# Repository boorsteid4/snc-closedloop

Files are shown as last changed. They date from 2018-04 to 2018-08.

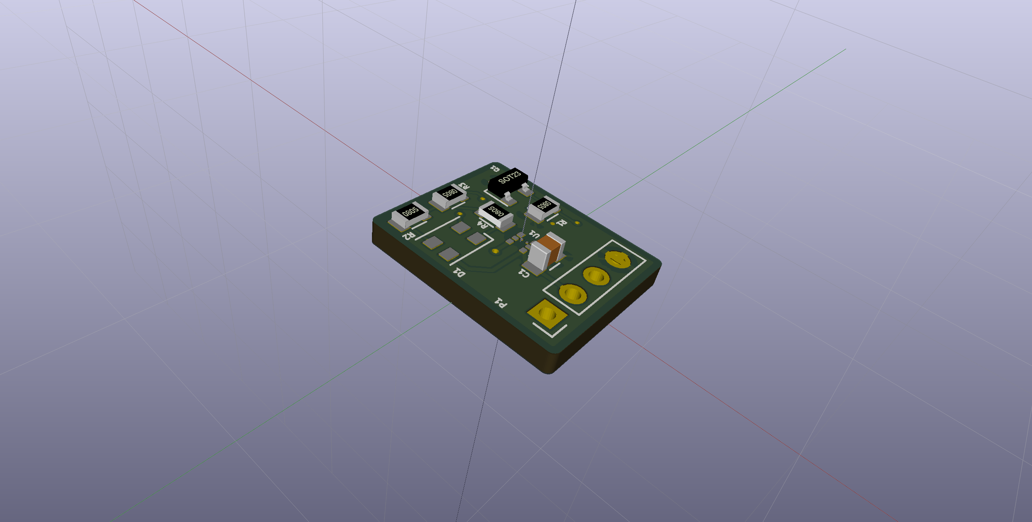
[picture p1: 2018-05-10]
Documentation/fig/LightBoardLayout.png

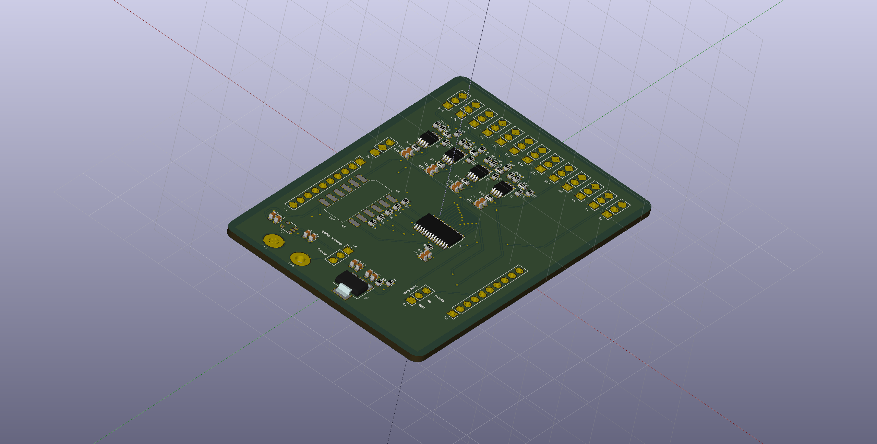
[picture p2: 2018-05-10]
Documentation/fig/LightBoardIMG.png

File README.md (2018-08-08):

# Automatic Light Dimming System
Welcome to the Git repo for our Systems and Control Spring 2018 final project! We are designing an automatic light dimming system with PID control. This top directory gives a general overview of the project.

## Contents

* [Hardware](#hardware)
* [Code Structure](#code-structure)
* [Documentation](#documentation)
* [PCB](#pcb)
* [SolidWorks](#solidworks)

## Hardware
The hardware for this project consists of:
* 1 MSP430FR2433 LaunchPad Development Kit by Texas Instruments
* 1 custom central control daughter card (CentralBoard)
* 13 custom LED/light sensor boards (LightBoard)  
    *  9 for the LED array  
    *  4 for the sensor array

The MSP430FR2433 serves as the processor on which the control system will be implemented. The daughter card includes an LED driver, transimpedance amplifiers for the light sensor inputs, and connectors for the power supply and motor. The transimpedance amplifiers were placed on the daughter card in order to minimize the space needed for each individual LightBoard since there will be so many of them placed inside our box. The LEDs and sensors were made into one board in an effort to minimize the cost of this project.

## Code Structure
* **main.c** - The top level entity of this project.
* **Controller.c/.h** - These files define a structure to contain all of the data that is necessary to implement a control system. It also includes a number of functions used to update the controls system.

Code can be found [here](Code).

## Documentation
[This subdirectory](Documentation) contains documentation for the project. Our project proposal, final report, and all refrences are contained herein. Images, figures, and hardware datasheets can also be found here. 

## PCB
PCBs were designed for this project. [This subdirectory](PCB) has all relevant project files, including schematics and layouts.

## SolidWorks
Solidworks designs created for the project thus far can be found in [this subdirectory](SLDWK).

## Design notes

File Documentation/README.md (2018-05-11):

# Documentation Catalog

| Author 	| Company Catalog No. 	| Description 		| Link				|
|---|---|---|:---:|
|Boorstein & Souder	|			|Project Proposal			 		|[Project Proposal](Final_Project_Proposal-Systems_and_Control.pdf)	|
|Boorstein & Souder  	|			|Final Project Report			 		|[Final Project Report](09321_1_Boorstein_Souder.pdf)		  	|
|Boorstein & Souder 	|			|Bill of Materials			 		|[BOM](bom/Bill-of-Materials.pdf)					|
|Boorstein & Souder  	|			|Light Board Bill of Materials		 		|[BOM](bom/LightBoard_BOM.pdf)				 	 	|
|Boorstein & Souder  	|			|Light Controller Bill of Materials	 		|[BOM](bom/LightController_BOM.pdf)					|
|Texas Instruments	|SLASE59B		|MSP430FR2433 Mixed-Signal Microcontroller  		|[DS](ds_ug/msp430fr2433.pdf)					 	|
|Damon Boorstein  	|			|System Block Diagram			 		|[FIG](fig/block_diagram.png)					 	|
|Lonnie Souder II 	|			|Light Controller Layout		 		|[FIG](fig/LightBoardIMG.png)					 	|
|Lonnie Souder II 	|			|Light Board Layout			 		|[FIG](fig/LightBoardLayout.png)					|
|Damon Boorstein 	|			|Light Controller UML			 		|[FIG](fig/LightControllerUML.png)					|
|C.M.Mak et. al.  	|			|Article on daylight and luminous comfort 		|[REF](refs/1-s2.0-S0360132314001978-main.pdf)				|
|Hwang & Kim	  	|			|Article on Samsung's new Green Building 		|[REF](refs/1420326x10392017.pdf)					|
|Lee et. al.	  	|			|Article on human response to illuminance variations	|[REF](refs/1420326x12446208.pdf)					|
|IEEE		  	|			|IEEE Std. 1789-2015					|[REF](refs/7118618.pdf)						|
|Lu et. al.	  	|			|Report on ZigBee-Based Lighting System			|[REF](refs/out.pdf)							|
|Lonnie Souder II 	|			|Light Board Schematic					|[SCH](schematic/LightBoardSchematic.png)				|
|Lonnie Souder II 	|			|Light Controller Schematic				|[SCH](schematic/LightControllerSchematic.png)				|
|Lonnie Souder II 	|			|Sensor Array Schematic					|[SCH](schematic/SensorArray.png)					|
|Lonnie Souder II 	|			|Example Transimpedance Amplifier Schematic		|[SCH](schematic/transimpedance_amp.png)				|
|Texas Instruments	|SLAU445G		|MSP430FR4xx and FR2xx Family User's Guide  		|[UG](ds_ug/slau445g.pdf)						|

### Legend

* AN - Application Note 
* DS - Datasheet 
* FIG - Figure/Image
* SCH - Schematic
* REF - Reference (Journal Article, Website, etc.)
* UG - User Guide

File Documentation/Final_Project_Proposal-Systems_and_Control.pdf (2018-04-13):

Damon Boorstein & Lonnie Souder II Dr. Al-Quzwini
Systems & Controls
March 26, 2018

Room Lighting Control System

For our final project we would like to implement an automatic room lighting control system. Instead of spending a large sum of money to light an entire room, we would like to recreate a small model of a room in a small box (roughly the size of a shoebox or slightly larger). This will allow us to set our focus on the control system instead or the logistics of lighting an entire room. The model will consist of a box that should be closed on all sides (just like any other house). On one side there will be a window consisting of automatic blinds that we plan to open and close with a small stepper or servo motor. At the top of the room there will be a light source (or possibly many light sources). There will also be light sensors inside the room and outside of the house. This will allow us to maintain full control over the level of brightness in the room at all times of day.
The basic functionality of the system is as follows. Because there is no “anti light” that we can use to dim the room even when the outside world is shining light through the window (disturbance), we have decided to use the shades to dim the room if necessary during the day, while the light source can light the room at night. For power efficiency, the system will always first take into account the desired brightness and the outside brightness. If the amount of light outside is sufficient to brighten the room to the desired level, then the light source should stay off completely and the shades will open to a point at which the room’s brightness is just right. If the outside light is not sufficient to brighten the room, then the light source will be used as a supplement.
The image below, is our rough draft model of the system as we see it so far (minus some conditionals to be implemented alongside the control system). Essentially our inputs are R1 and R2 which represent the voltage inputs to the light source and the motor controlling the blinds respectively. G1 represents the physical characteristics of the light source and its ability to convert power to light. H1 is our transfer function based off of the indoor brightness reading which is used to close the loop. G2 represents the blinds and how much light they allow through at certain angles. H2 is our transfer function based off of the outdoor brightness measurement and desired brightness, which will control the angle of the shades. As mentioned before, this is a rough model, and pieces may still be removed or added before the final submission as we find that pieces of our model are either incorrect or unnecessary.

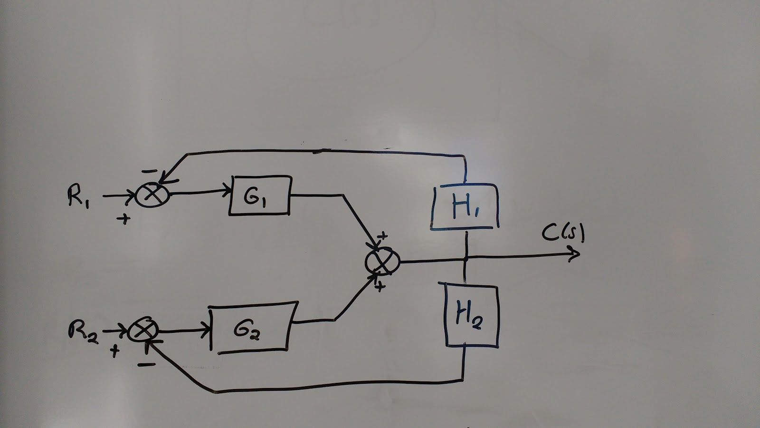
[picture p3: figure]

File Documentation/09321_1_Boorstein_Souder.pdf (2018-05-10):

– ECE 09.321: Systems and Controls –

## Automatic Light Dimming Control System Based on PID Control Design

L. Souder and D. Boorstein Section 1

May 8, 2018

## 1 Abstract

Demand for light dimming control systems is predicted to grow in the coming years with the rise in green buildings and green engineering. Current light dimming systems do not address the issue of high fluctuations in light level which can have damaging effects on occupants’ eyes. This can also affect occupants’ mental health, stress level, and productivity in the work environment. This report presents a design for a novel light dimming system based on software-implemented PID control theory. A central MSP430FR2433 is programmed to implement PID control for a negative feedback system consisting of an array of LEDs and current-output light sensors. PCBs were designed and printed. However, a final product was not fully built or tested due to several roadblocks and constraints. A fully designed system could definitely be built with additional time and effort.

## 2 Introduction

Sick building syndrome (SBS) is a condition often related to decreased productivity and increased stress, supposedly caused by deterioration of one’s interior environment [1]. This can be caused by a number of factors, including indoor lighting. Indoor lighting is an often overlooked design consideration in modern residential and work spaces, and its impact is significant on productivity and health. The Occupational Safety and Health Administration (OSHA) measures general lighting in the workplace using foot-candles as units, requiring physical plants maintain 10 foot-candles of brightness and offices at least 30 foot-candles [2]. In labor-intense environments like manufacturing plants, factories, or workshops, proper lighting ensures accident prevention, hazard avoidance, and physical safety. In the office, where these dangers are often not present, lighting contributes directly to mental health which influences

L. Souder and D. Boorstein | – ECE 09.321: Systems and Controls – | Section 1

productivity [1],[3],[4].

In 2009, Samsung World Headquarters in Seoul, Korea launched a new Energy Saving Campaign and earned the highest ranking Green Building Certification System certification by the Korean Green Building Council (KGBC). During daylight hours, half of the interior lights in the building were to be turned off to reduce power consumption [1]. During sunny days, this was no issue; during cloudy days, however, the offices were dark. This significantly affected employee mood and contributed to their annoyance ratio of their workplace [1]. Daylight can certainly improve mood and has even shown to prevent certain diseases and influence window design in residential and office buildings [3]. However, visual distractions, variation in illuminance, and high stimulation caused by improper lighting may contribute to higher amounts of annoyance and stress [4]. Higher stress can lead to decreased productivity.

As green engineering and green buildings become more popular in the coming years, the demand for light dimming control systems should also increase. Current light dimming control systems offer illumination at a fraction of the energy cost. A recent Zigbee-based indoor light control system was developed using a network of lightsensitive diodes and a central MSP430F2619 microprocessor and CC2430 RF chip. Mapping and modulation of the network was determined by the Zigbee standard, which is based on the IEEE 802.15.4 standard [5]. Novel systems like these should take into account not only the level of brightness, but also the uniformity of brightness, how often brightness in the room varies during the day, and how quickly the system responds to change. The focus of these systems should be to achieve a comfortable medium between energy savings and occupant’s comfort.

Therefore, a control system with proper transient behavior which addresses this issue must be developed in order to ensure the well-being of the occupants is secured while still maintaining proper light level and also saving energy. This report presents a design for a novel light dimming control system based on classical PID control. A system was to be constructed inside of a 1 cubic foot box and would contain an array of LED, motorized blinds, and a feedback sensor array. The primary function of the system would be to maintain a constant brightness in the room, using first and foremost the blinds to allow daylight into the room and compensating with the LED until a target brightness was achieved. A second-order design goal for the system would be to demonstrate proper compensator design to achieve a transient behavior which would not cause eye strain for the room’s occupants. Compensation of the system was to be implemented using a central microcontroller with its own independent power supply for ease of transportation and setup.

## 3 Standards And Constraints

This section discusses the standards, regulations, and constraints of the project.

Automatic Light Dimming Control System Based on PID Control Design | 2

L. Souder and D. Boorstein | – ECE 09.321: Systems and Controls – | Section 1

### 3.1 Standards and Regulations

Code for the software control system, which is written in C, conforms to the current standard for the C programming language, the ISO/IEC 9899:2011 or C11 [6].

This system is intended for demonstration only. However, the principals employed here could be up-scaled to a consumer product in a house or office space. Therefore, this design adopts several standards to ensure occupant safety. This project adheres to IEEE 1789-2015 Recommended Practices for Modulating Current in High Brightness LEDs for Mitiagting Health Risks to Viewers [7].

### 3.2 Constraints

It was originally intended for this system to be self-contained inside of a 1 cubic foot box. Completely independent of any external power, it was to posses its own transportable power supply. This was much less a constraint and more a criterion, however it did provide direction for the design.

Another constraint of the project was the use of the TI MSP430 line of microprocessors as opposed to an Arduino. The Arduino microprocessors are arguably much easier to program when compared to the C-code structure required for MSP430 microprocessors. What initially appeared as a time constraint eventually became a boon. This inevitably lead to the creation of a much more robust library of functions for the purpose of PID tuning written in C.

The foremost constraint of the project was the number of printed circuit boards that needed to be assembled for the system to work. There were, in total, 14 separate PCB with surface mount components to be hand-soldered. Without these components, there was no system, because these boards contained the lights, light sensors, and central processing unit with power supply. The LEDs only came in a surface mounted package, which made PCB design necessary. Because these components were not assembled, the system itself was not realized nor tested. This was a major hindrance of the project, as it prevented actual PID implementation and demonstration of the design.

The system was also planned to have an opening on one of the sides with controllable vertical blinds, simulating daylight for the room. The complexity of this design became a hassle, especially with the limited time of the project, and this idea was ultimately put aside. In order to maintain a controlled environment inside the room, the cutout which would house the motorized blinds was also done away with. This constrained the design in two ways: (1) there was now no way to see inside the box to tell if the control system was working, and (2) there was no way to add disturbance to the system to identify proper PID compensation. Some ideas which were generated but unfortunately never implemented included:

- adding cameras to the inside of the box to be able to monitor the interior,
Automatic Light Dimming Control System Based on PID Control Design | 3

L. Souder and D. Boorstein | – ECE 09.321: Systems and Controls – | Section 1
- cutting small holes in multiple parts of the box with slider shutters to simulate disturbance into the system, and
- manually changing the brightness on certain lights and forcing the other lights to compensate for this disturbance (essentially using a ”broken” light)

## 4 Control Design

This section discusses the characterization of the control system. It includes a discussion on the development of the system thus far, the design goals for the system, and control loop implementation. Listed here are some of the original design goals for the system despite any constraints that arose during development of the project, such as time and material constraints.

### 4.1 System Characterization

The system is characterized by an open loop interior light level determined by a feedback light sensor array, producing a closed-loop control system. A central microprocessor is to receive the input, output, and error signal of the closed-loop system. The design is to be compensated using a software-based PID compensator through the microprocessor.

### 4.2 Design Goals

The goal of the interior light dimming system is to achieve, first and foremost, a target brightness and uniformity in the room. This is to be accomplished through separate communications to each LED based on feedback through light sensors located on the floor of the box. The transient behavior of the system is then to be tuned using PID control implemented through software on the microcontroller’s internal processor. The overall transient behavior of the system is to be slow so that the rate of change of the system does not irritate or strain the eyes.

### 4.3 Control Loop Implementation

An MSP430FR2433 serves as the control loop in this system. Control functions are to be implemented through software. A library of functions was written in C to calculate all necessary constants and variables for a PID controller, including errors and gains.

For example, the error signal was calculated by subtracting the the output reading from the target variable of the controller on line 17 of Controller.c. This value is then assigned to the an error variable of the controller.

int calcError ( struct & Controller controller , int outputReading ) {
int error = controller . target - outputReading ;
Automatic Light Dimming Control System Based on PID Control Design | 4

L. Souder and D. Boorstein | – ECE 09.321: Systems and Controls – | Section 1
| controller . e = error ; return error ;

}

The integral error is calculated by multiplying the error by a user-defined time step.

int calcIntError ( struct & Controller controller , int outputReading , int timeStep , int error ) {
| int int_error = error * timeStep ; controller . int_e += int_error ; return int_error ;

}

Derivative error is found by taking the rate of change of the error signal over the time step.

int calcdError ( struct & Controller controller , int outputReading , int timeStep , int error ) {
| int deltaError = error - controller . y ; int rate = deltaError / timeStep ; controller . de = rate ; return rate ;

}

These functions allow for calculation of total PID error in a single function.

void calcPID ( struct & Controller controller int outputReading , int timeStep ) {
int error = calcError ( controller , outputReading ) ; calcIntError ( controller , outputReading , timeStep ,
| error ) ;
calcdError ( controller , outputReading , timeStep ,
| error ) ;
}

Finally, an update function was created to automatically recalculate PID error each time step.

void updateDriver ( struct & Controller controller , int outputReading , int timeStep ) {
calcPID ( controller , outputReading , timeStep ) ;
controller . driver = | ( controller . Kp *
| controller . e ) + ( controller . Ki * controller . int_e ) -

( controller . Kd * controller . de ) ;
}
Automatic Light Dimming Control System Based on PID Control Design | 5

L. Souder and D. Boorstein | – ECE 09.321: Systems and Controls – | Section 1

## 5 Design Discussion

The microprocessor chosen for this design was the MSP430FR2433. This is one of the latest microprocessors in the MSP430 line from TI and features optimized ultralow power sleep modes and ferroelectric RAM for increased energy efficiency. It also has support for an external 32kHz crystal oscillator and more than enough I/O pins [8]. This makes the FR2433 practical for this design. Nine ASMB-MTB1-0A3A2 LEDs and four PNJ4K01F current-output light sensors were used for this design. The PCA9685 LED driver was chosen to drive the LEDs. A 6-switch Dip-Switch package was included in the design for selection of the LED driver address. This served as a safety mechanism to safeguard against accidentally permanently selecting an address during the design process and then finding out it was a reserved address later on.

An overall UML for the light controller system is given in Fig. 1. The FR2433 serves as the central control system where software PID control is to be implemented.

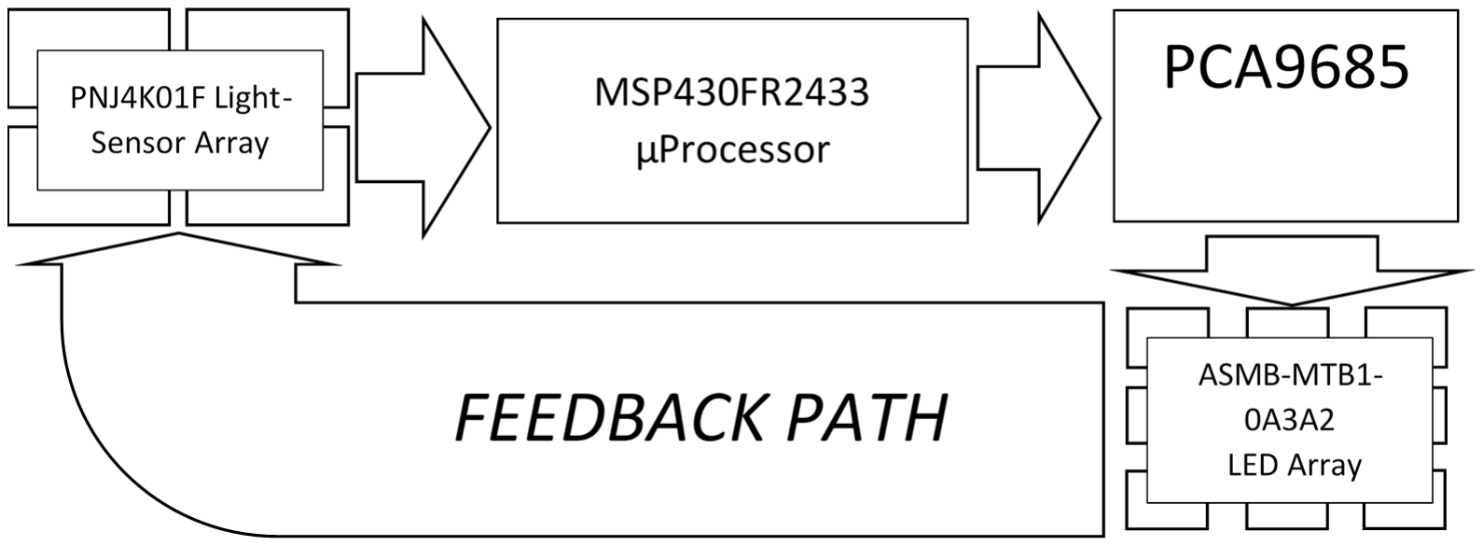
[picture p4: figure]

Figure 1: UML for the Light Controller

A 9V battery supply was chosen as the primary method of supplying power to all circuits. This was selected as 9V batteries are easily obtainable and replaceable in case of failure. The light sensors and LEDs required a +5V power supply, which necessitated a voltage regulator. The LM317 was chosen due to its frequent use in other circuits and the authors’ experience with the device. Similarly with the FR2433, which required a supply of +3.3V supply, another linear regulator – namely the NCP551 – was selected. All components purchased for this design were surface-mount, which prompted PCB design.

Open source PCB design software, KiCAD, was used to design the PCB for the controller circuit and individual light boards. Overall circuit diagrams for the light controller and individual light boards are given in Section 7 in Fig. 5 and Fig. 6, respectively. The central PCB is intended to serve as a LaunchpadTM daughter card for convenient programming of the off-board microprocessor chip. The design for the controller board can be seen in Fig. 2. For the design of a single light board, see Fig. 3. You will notice

Automatic Light Dimming Control System Based on PID Control Design | 6

L. Souder and D. Boorstein | – ECE 09.321: Systems and Controls – | Section 1

that the light boards include all of the necessary pads and connections for both an LED and an ambient light sensor. This was done solely to cut back on costs, since each individual design adds to the price. In practice, we would use 4 boards with just a sensor for our sensor array, and 9 boards with just an LED for our LED array.

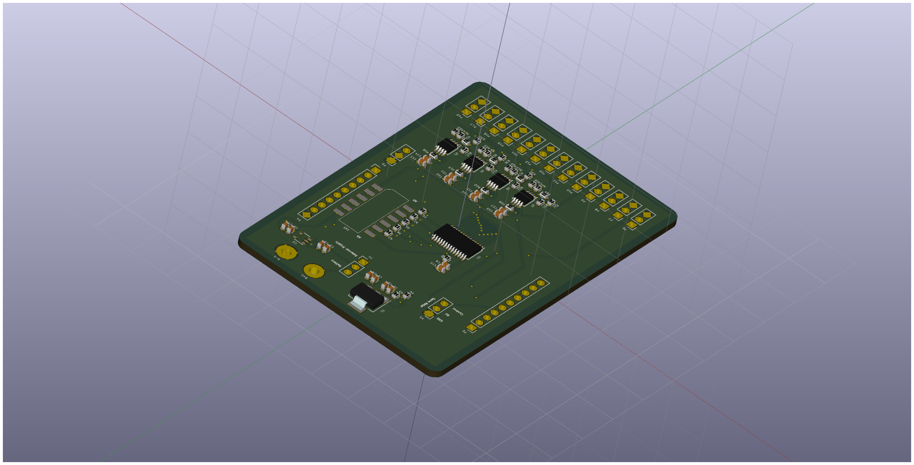
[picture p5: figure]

Figure 2: Light controller daughter card model

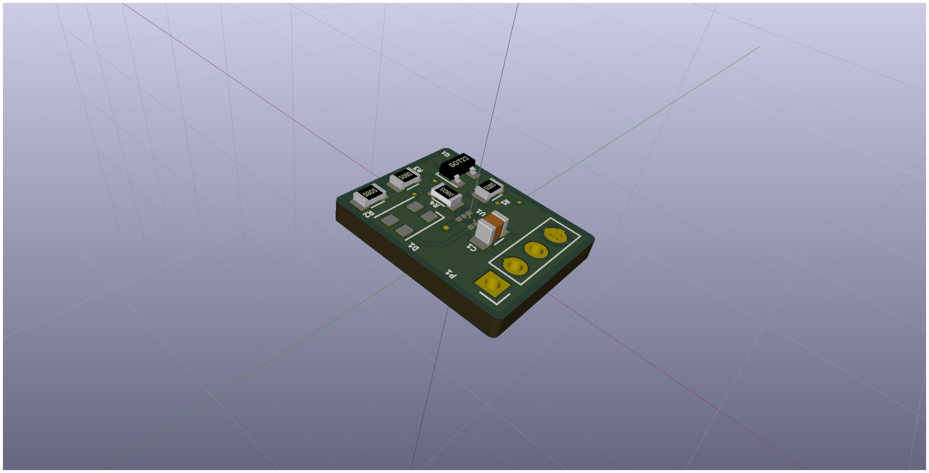
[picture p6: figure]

Figure 3: LED light board model

Design of the system began with software implementation of PID control. This was completed using TI’s dedicated IDE for MSP430 processors, Code Composer Studio. Code for the control system is discussed in Section 4.3. Further coding was required

Automatic Light Dimming Control System Based on PID Control Design | 7

L. Souder and D. Boorstein | – ECE 09.321: Systems and Controls – | Section 1

for microprocessor register initialization, such as the FR2433’s internal ADC.

A full block diagram for the system is given in Fig. 4. Gains KP , Ki
| | , and Kd are
parameter gains determined through PID tuning. The system must first convert a target light level to a voltage through use of a transimpedance amplifier. After PID compensation, the system then converts this voltage signal into light through the LED circuit. This light is fed back through the sensor array, producing a negative feedback control.

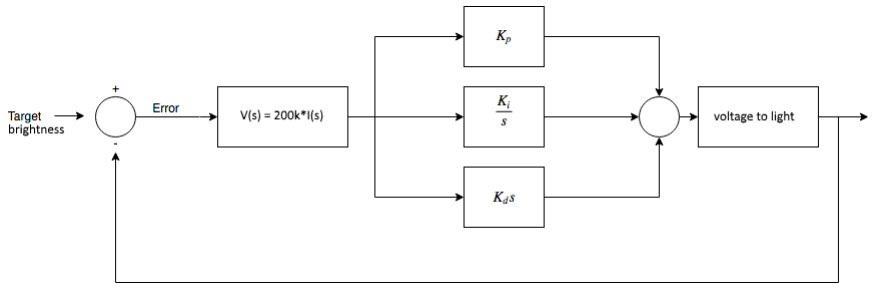
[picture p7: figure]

Figure 4: Block diagram of the system

## 6 Results and Conclusions

Code for the software control loop and a library of functions was written. Several PCB were printed and parts delivered. At the current time of writing, the project is unfinished. The system was never tested, unfortunately, because the PCB have not been assembled due to scheduling conflicts within the Tech Office. However, all the parts are currently in the possession of the authors and can be assembled. The authors anticipate that this system will operate correctly without much more work and that all that is left to do is manually tune each parameter gain of the PID controller.

The design here nonetheless presents a framework for future designs. This report stresses the importance of choosing proper transient behavior for the system to prevent eye-strain and promote psychological wellness for indoor occupants. Design through PID compensation aids in this effort, as one can choose different gain values for each gain stage (proportional, integral, and derivative) to achieve a desired transient and steady-state behavior.

### 6.1 Work Distribution Summary

Damon Boorstein

- Parts shopping
- Register initialization code
Automatic Light Dimming Control System Based on PID Control Design | 8

L. Souder and D. Boorstein | – ECE 09.321: Systems and Controls – | Section 1
- Main author of this report

Lonnie Souder II

- Wrote libraries for PID controller
- Designed light controller and main board schematics
- Designed light controller and main board PCBs

### 6.2 GitHub Link

A link to this project’s Git repository can be found here: https://github.com/boorsteid4/snc-closedloop

Automatic Light Dimming Control System Based on PID Control Design | 9

L. Souder and D. Boorstein | – ECE 09.321: Systems and Controls – | Section 1

## 7 Appendix A: Code

/*
* Controller .c
*
* Lonnie L. Souder II
* 04/13/2018
*
* This file defines a data structure which contains all the necessary
* data for a PID controller including gain constants and rolling
* sums for error , integral of error , and derivative of error .
* In addition , this file will include methods used to derive and manipulate
* all of data collected by the PID controller
*/

# include " Controller .h"

int calcError ( struct & Controller controller , int outputReading ) {
int error = controller . target - outputReading ; controller . e = error ;
return error ;
}

int calcIntError ( struct & Controller controller , int outputReading , int timeStep ) {
int error = calcError ( controller , outputReading ) ; int int_error = error * timeStep ;
controller . int_e += int_error ;
return int_error ;
}

int calcIntError ( struct & Controller controller , int outputReading , int timeStep , int error ) {
int int_error = error * timeStep ; controller . int_e += int_error ; return int_error ;
}

int calcdError ( struct & Controller controller , int outputReading , int timeStep ) {

Automatic Light Dimming Control System Based on PID Control Design | 10

L. Souder and D. Boorstein | – ECE 09.321: Systems and Controls – | Section 1
| int error = calcError ( controller ,
outputReading ) ; | // current error
| int deltaError = error - controller . y ; int rate = deltaError / timeStep ; controller . de = rate ; return rate ;

}

int calcdError ( struct & Controller controller , int outputReading , int timeStep , int error ) {
| int deltaError = error - controller . y ; int rate = deltaError / timeStep ; controller . de = rate ; return rate ;

}

void calcPID ( struct & Controller controller int outputReading , int timeStep ) {
int error = calcError ( controller , outputReading ) ; calcIntError ( controller , outputReading , timeStep ,
| error ) ;
calcdError ( controller , outputReading , timeStep ,
| error ) ;
}

void updateDriver ( struct & Controller controller , int outputReading , int timeStep ) {
calcPID ( controller , outputReading , timeStep ) ;
controller . driver = | ( controller . Kp *
| controller . e ) +
| | ( controller . Ki
*
| | controller . int_e )
| | ( controller . Kd
*
| | controller . de ) ;
}

/* ************************************* * Helper Functions for PWM Controller ************************************** */

int Clamp (& int subject , int min , int max ) { if ( subject > max )

Automatic Light Dimming Control System Based on PID Control Design | 11

L. Souder and D. Boorstein | – ECE 09.321: Systems and Controls – | Section 1
| subject = max ; else if ( subject < min ) subject = min ; return subject ;

}

void updateDriver ( struct & Controller controller , int outputReading , int timeStep ) {
calcPID ( controller , outputReading , timeStep ) ;
controller . driver = | ( controller . Kp *
| controller . e ) +
| | ( controller . Ki
*
| | controller . int_e )
| | ( controller . Kd
*
| | controller . de ) ;
Clamp ( controller . driver , 0 , controller . driverMax ) ; }
Automatic Light Dimming Control System Based on PID Control Design | 12

L. Souder and D. Boorstein | – ECE 09.321: Systems and Controls – | Section 1

## 8 Appendix B: Schematics

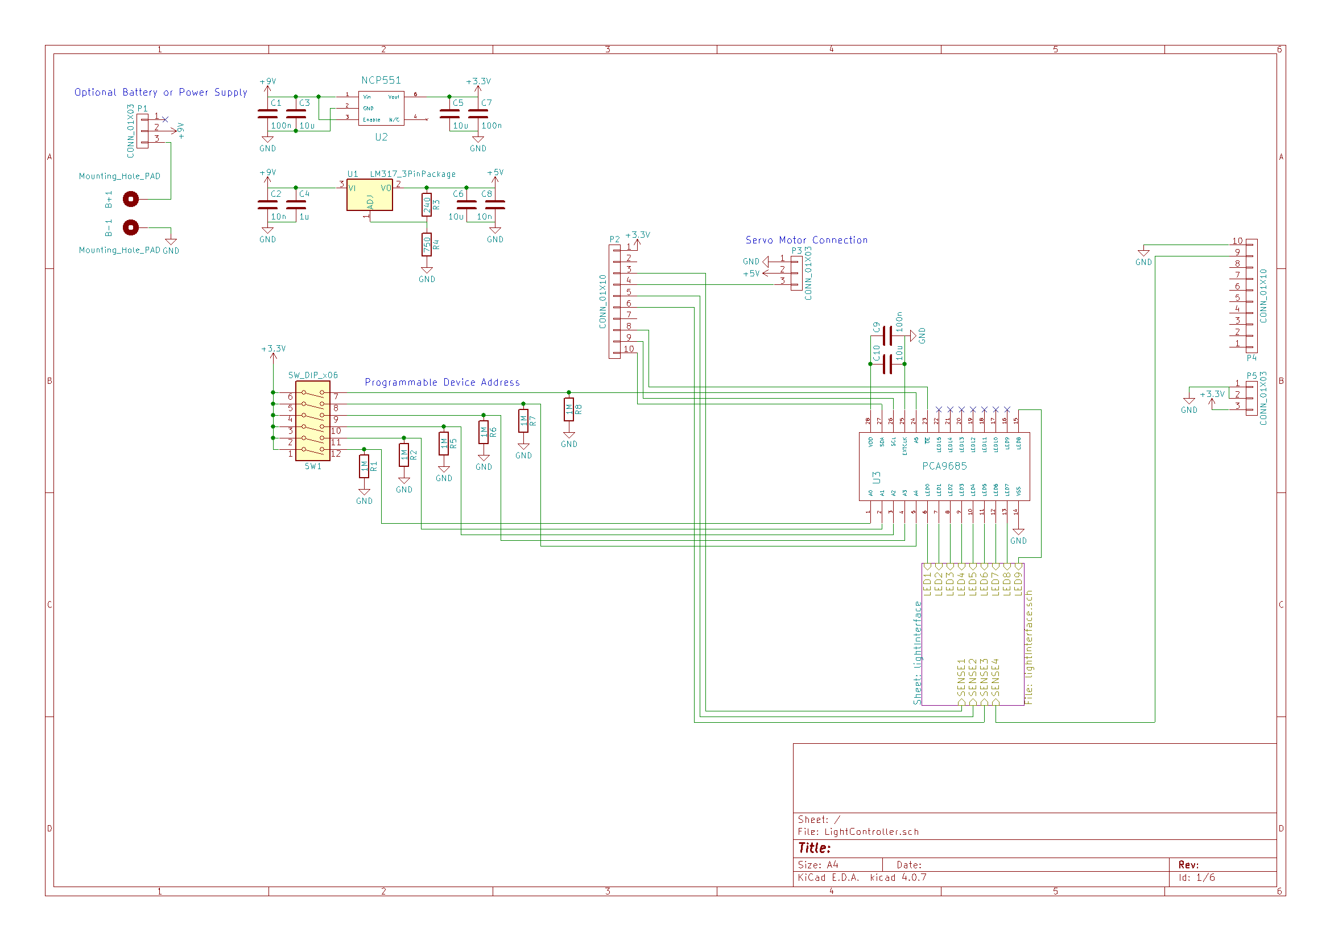
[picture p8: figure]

Figure 5: Schematic for the Light Controller

Automatic Light Dimming Control System Based on PID Control Design | 13

L. Souder and D. Boorstein | – ECE 09.321: Systems and Controls – | Section 1

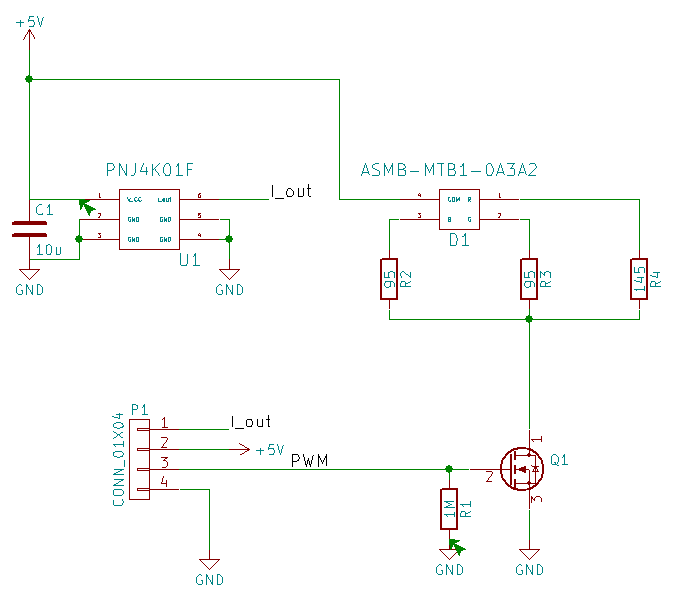
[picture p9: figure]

Figure 6: Schematic for Light Board

Automatic Light Dimming Control System Based on PID Control Design | 14

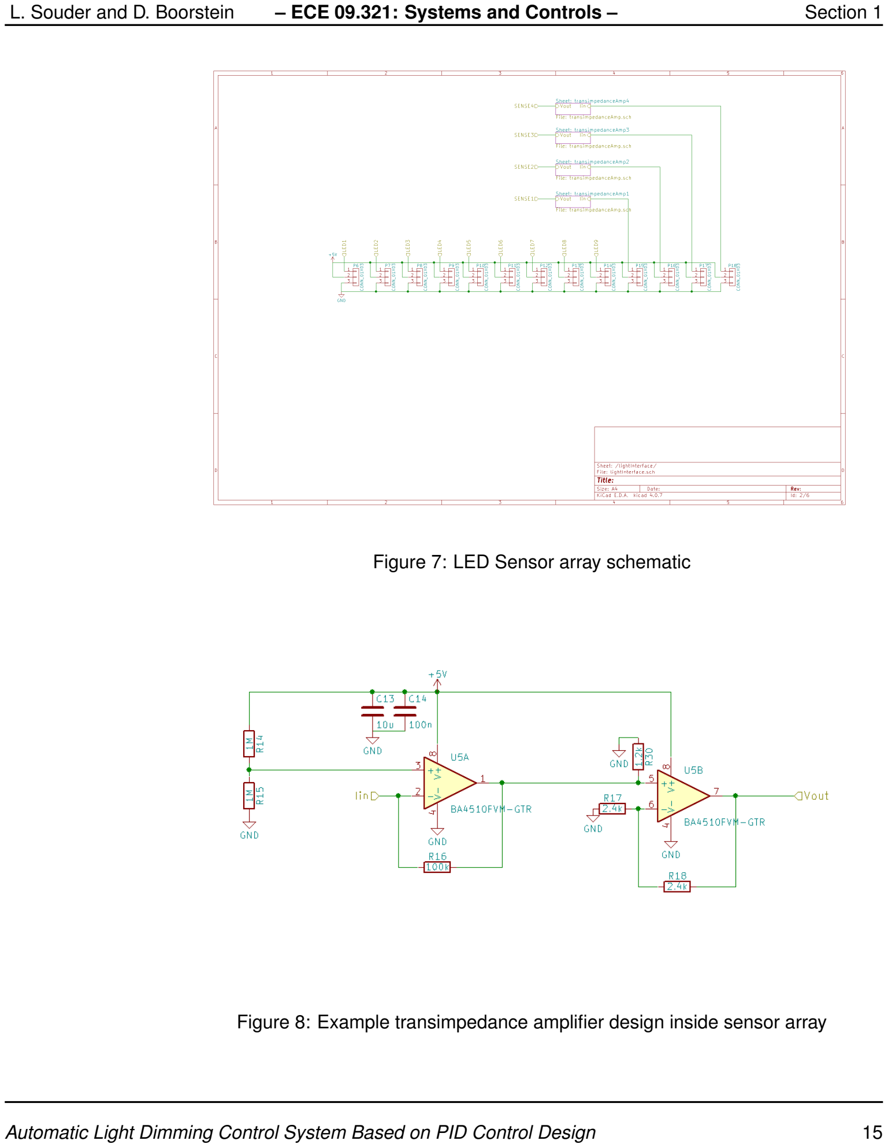
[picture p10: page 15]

L. Souder and D. Boorstein | – ECE 09.321: Systems and Controls – | Section 1

Figure 7: LED Sensor array schematic

Figure 8: Example transimpedance amplifier design inside sensor array

Automatic Light Dimming Control System Based on PID Control Design | 15

L. Souder and D. Boorstein | – ECE 09.321: Systems and Controls – | Section 1

## References

[1] T. Hwang and T. K. Jeong, “Effects of indoor lighting on occupants visual comfort and eye health in a green building,” Indoor and Built Environment, vol. 20, no. 1, pp. 75–90, 2011. doi: 10.1177/1420326X10392017; 05.
[2] J. Williams, “Requirements for workplace lighting,” Aug 3, 2010.
[3] P. Xue, C. M. Mak, and H. D. Cheung, “The effects of daylighting and human behavior on luminous comfort in residential buildings: A questionnaire survey,” 2014. ID: 271434.
[4] J.-H. Lee, Y. Yoon, Y.-K. Baik, and S. Kim, “Analyses on human responses to illuminance variations for resident-friendly lighting environment in a small office,” Indoor and Built Environment, vol. 22, no. 3, pp. 535–550, 2013. doi: 10.1177/1420326X12446208; 05.
[5] C. Z. Lu, X. Yang, and W. Pan, “A zigbee-based indoor intelligent lighting system research and design,” Applied Mechanics and Materials, vol. 71-78,
p. 2276, 2011. Source type: scholarlyjournals; Object type: Article; Object type: Feature; Copyright: Copyright Trans Tech Publications Ltd. Jul 2011; DO-CID: 3105622361; PCID: 81499262; PMID: 205230; ProvJournalCode: LMCM; DOI: 10.4028/www.scientific.net/AMM.71-78.2276; DocISBN: 978-3-03785-203-3; PublisherXID: ICATTPL LMCM V7178 20110701 B794667EB66B7DF972358.
[6] Wikipedia contributors, “C11 (c standard revision) — Wikipedia, the free encyclopedia,” 2018. [Online; accessed 7-May-2018].
[7] IEEE, “Recommended practices for modulating current in high-brightness leds for mitigating health risks to viewers,” IEEE Std 1789-2015, pp. 1–80, June 2015.
[8] TI, MSP430FR2433 Mixed-Signal Microcontroller, 6 2017.
Automatic Light Dimming Control System Based on PID Control Design | 16

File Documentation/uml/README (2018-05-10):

uml.sty is a package for writing UML (Unified Modelling Language) 
diagrams in LaTeX. Currently, it implements a subset 
of class diagrams, and some extra constructs as well. 
The example on the right hand demonstrates the 
Schema constructs. 

Run the Makefile or alternative:

latex uml.ins
latex uml.dtx
makeindex -s gind.ist uml
makeindex -s gglo.ist -o uml.gls uml.glo
latex uml.dtx
dvips uml.dvi
ps2pdf uml.ps

This version of uml uses the extended version of the keyval 
package. So be sure that you 
- have installed xkeyval with the special pst-xkey.tex
  (CTAN: tex-archive/macros/latex/contrib/xkeyval/)
- do not load another package after uml, which loads
  the old keyval.sty or pst-key.tex

--
Herbert Voss 2006-11-23

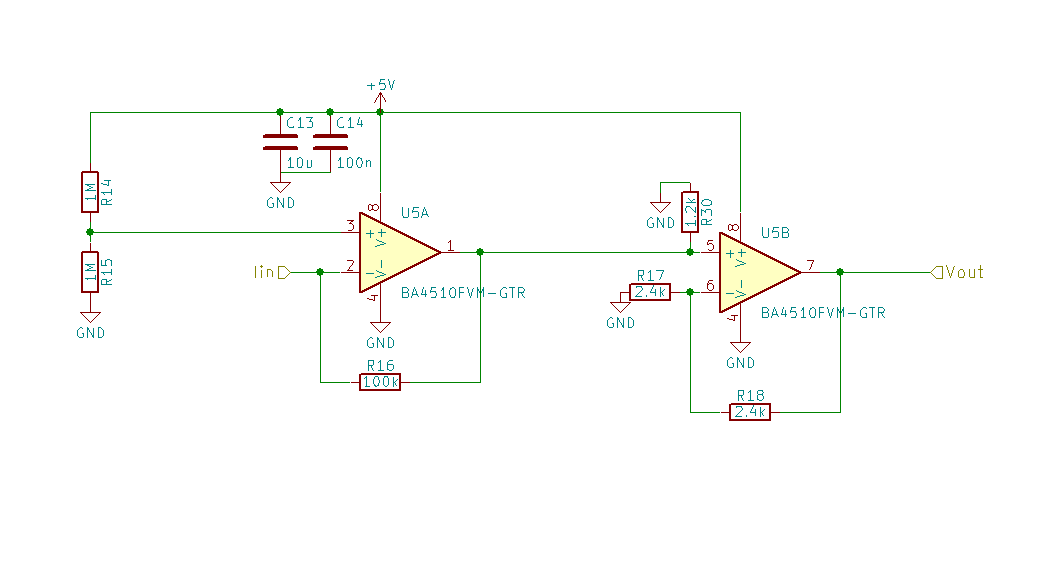
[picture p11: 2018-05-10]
Documentation/schematic/transimpedance_amp.png

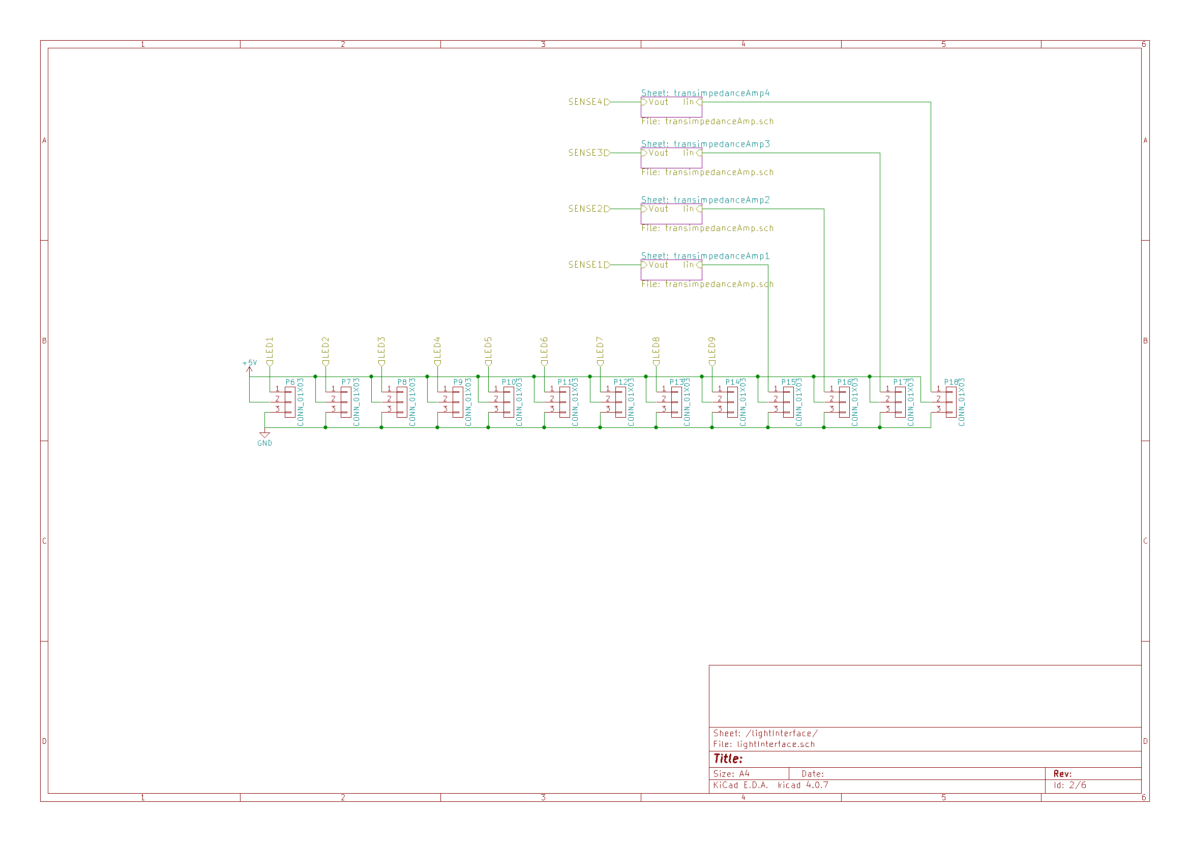
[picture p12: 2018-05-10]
Documentation/schematic/SensorArray.png

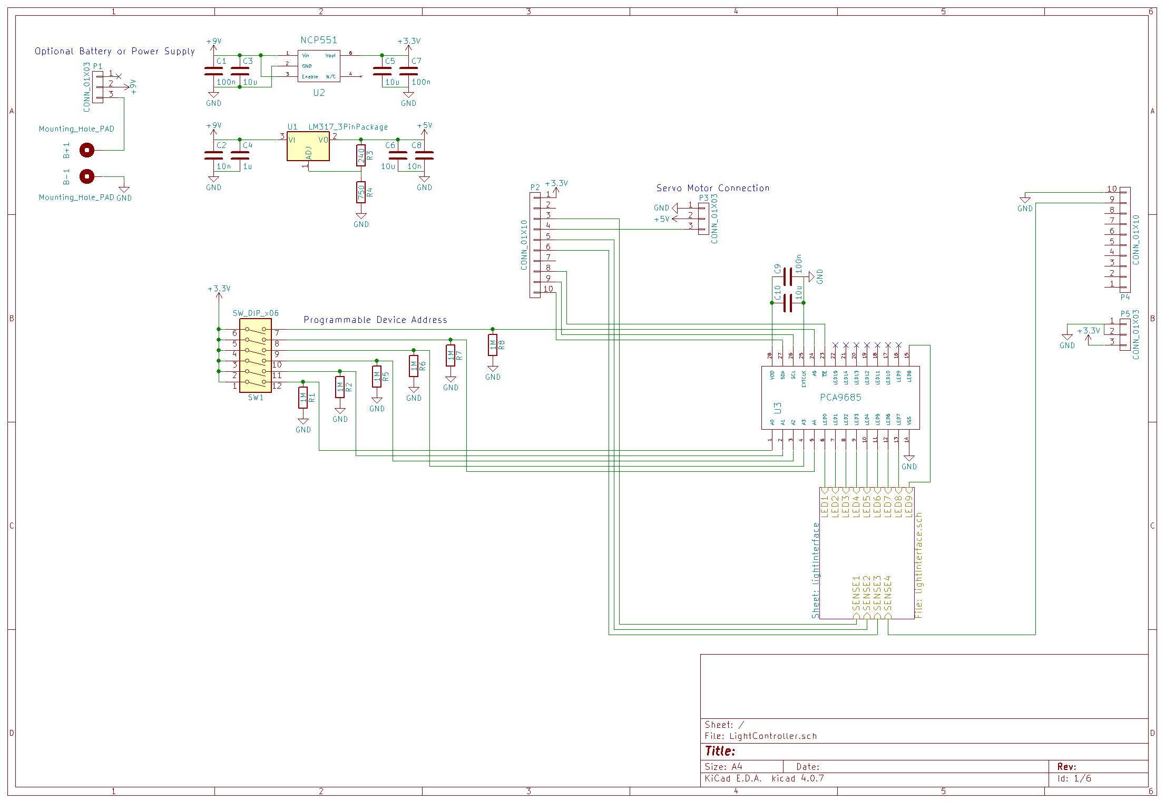
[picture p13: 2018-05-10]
Documentation/schematic/LightControllerSchematic.png

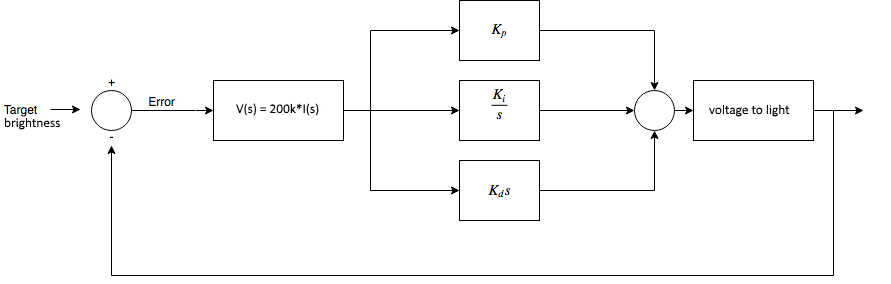
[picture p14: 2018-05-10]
Documentation/fig/block_diagram.png

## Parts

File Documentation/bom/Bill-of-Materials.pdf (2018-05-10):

Id | Designator | Package | Quantity | Designation | Supplier and ref
| 1 C1 | C_0805 | | 1 10u
2 D1 | LED_Cree-PLCC4_3.2x2.8mm_CCW | 1
3 P1 | Pin_Header_Straight_1x04_Pitch2.54mm | 1
4 Q1 | SOT-23 | 1
| 5 R1 | R_0805 | | 1 1M
| 6 R2 | R_0805 | | 1 95
| 7 R3 | R_0805 | | 1 95
| 8 R4 | R_0805 | | 1 145
| 9 U1 | PNJ4K01F | | 1 PNJ4K01F

Column1 _1

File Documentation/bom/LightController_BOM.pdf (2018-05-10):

Id | Designator | Package | Quantity
1 | B+1;B-1 | MountingHole_2.2mm_M2_Pad | 2
2 P1;P3;P5;P6;P7;P8;P9;P10;P11;P12;P13;P14;P15;P16;P17;P18 Pin_Header_Straight_1x03_Pitch2.54mm | 16
3 P2;P4 Pin_Header_Straight_1x10_Pitch2.54mm | 2
4 SW1 DIP_SW_219-6LPST | 1
5 U1 SOT-223 | 1
6 U2 TSOP-5_1.65x3.05mm_Pitch0.95mm | 1
7 U3 TSSOP-28_4.4x9.7mm_Pitch0.65mm | 1
8 U4;U5;U6;U7 MSOP-8_3x3mm_Pitch0.65mm | 4
9 C1;C7;C9;C12;C14;C16;C18 C_0603 | 7
10 C2;C8 C_0603 | 2
11 C3;C5;C6;C10;C11;C13;C15;C17 C_0603 | 8
12 C4 C_0603 | 1
13 R1;R2;R5;R6;R7;R8;R9;R10;R14;R15;R19;R20;R24;R25 R_0603 | 14
14 R3 R_0603 | 1
15 R4 R_0603 | 1
16 R11;R16;R21;R26 R_0603 | 4
17 R12;R17;R22;R27 R_0603 | 4
18 R13;R18;R23;R28 R_0603 | 4

From KiCAD

Designation | Supplier and ref
Mounting_Hole_PAD
CONN_01X03 | Digikey 732-5316-ND
CONN_01X10 | Digikey WM4008-ND
SW_DIP_x06 | Digikey CT2196LPST-ND
LM317_3PinPackage | Digikey 296-12602-ND
NCP551 | Digikey NCP551SN33T1GOSCT-ND
PCA9685 | Digikey 568-11925-1-ND
BA4510FVM-GTR | Digikey BA4510FVM-GTRCT-ND
100n | Digikey 490-1532-1-ND
10n | Digikey 1276-1928-1-ND
10u | Digikey 1276-1119-1-ND
1u | Digikey 1276-1184-1-ND
0 | Digikey RMCF0603FFG1M00CT-ND
240 | Digikey RMCF0603FT240RCT-ND
750 | Digikey RMCF0603FT750RCT-ND
10k | Digikey RMCF0603FT10K0CT-ND
2.4k | Digikey RMC0603JT2K40CT-ND
5.1k | Digikey RMC0603FT5K10CT-ND

Ordered

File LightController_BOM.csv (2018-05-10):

From KiCAD
Id | Designator | Package | Quantity | Designation | Supplier and ref
1 | B+1;B-1 | MountingHole_2.2mm_M2_Pad | 2 | Mounting_Hole_PAD
2 | P1;P3;P5;P6;P7;P8;P9;P10;P11;P12;P13;P14;P15;P16;P17;P18 | Pin_Header_Straight_1x03_Pitch2.54mm | 16 | CONN_01X03 | Digikey 732-5316-ND
3 | P2;P4 | Pin_Header_Straight_1x10_Pitch2.54mm | 2 | CONN_01X10 | Digikey WM4008-ND
4 | SW1 | DIP_SW_219-6LPST | 1 | SW_DIP_x06 | Digikey CT2196LPST-ND
5 | U1 | SOT-223 | 1 | LM317_3PinPackage | Digikey 296-12602-ND
6 | U2 | TSOP-5_1.65x3.05mm_Pitch0.95mm | 1 | NCP551 | Digikey NCP551SN33T1GOSCT-ND
7 | U3 | TSSOP-28_4.4x9.7mm_Pitch0.65mm | 1 | PCA9685 | Digikey 568-11925-1-ND
8 | U4;U5;U6;U7 | MSOP-8_3x3mm_Pitch0.65mm | 4 | BA4510FVM-GTR | Digikey BA4510FVM-GTRCT-ND
9 | C1;C7;C9;C12;C14;C16;C18 | C_0603 | 7 | 100n | Digikey 490-1532-1-ND
10 | C2;C8 | C_0603 | 2 | 10n | Digikey 1276-1928-1-ND
11 | C3;C5;C6;C10;C11;C13;C15;C17 | C_0603 | 8 | 10u | Digikey 1276-1119-1-ND
12 | C4 | C_0603 | 1 | 1u | Digikey 1276-1184-1-ND
13 | R1;R2;R5;R6;R7;R8;R9;R10;R14;R15;R19;R20;R24;R25 | R_0603 | 14 | 0 | Digikey RMCF0603FFG1M00CT-ND
14 | R3 | R_0603 | 1 | 240 | Digikey RMCF0603FT240RCT-ND
15 | R4 | R_0603 | 1 | 750 | Digikey RMCF0603FT750RCT-ND
16 | R11;R16;R21;R26 | R_0603 | 4 | 10k | Digikey RMCF0603FT10K0CT-ND
17 | R12;R17;R22;R27 | R_0603 | 4 | 2.4k | Digikey RMC0603JT2K40CT-ND
18 | R13;R18;R23;R28 | R_0603 | 4 | 5.1k | Digikey RMC0603FT5K10CT-ND
 |  |  |  | Ordered

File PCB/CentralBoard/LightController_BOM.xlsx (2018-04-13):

Id | Designator | Package | Quantity | Designation | Supplier and ref
1 | B+1;B-1 | MountingHole_2.2mm_M2_Pad | 2 | Mounting_Hole_PAD
2 | P1;P3;P5;P6;P7;P8;P9;P10;P11;P12;P13;P14;P15;P16;P17;P18 | Pin_Header_Straight_1x03_Pitch2.54mm | 16 | CONN_01X03
3 | P2;P4 | Pin_Header_Straight_1x10_Pitch2.54mm | 2 | CONN_01X10
4 | SW1 | DIP_SW_219-6LPST | 1 | SW_DIP_x06
5 | U1 | SOT-223 | 1 | LM317_3PinPackage
6 | U2 | TSOP-5_1.65x3.05mm_Pitch0.95mm | 1 | NCP551
7 | U3 | TSSOP-28_4.4x9.7mm_Pitch0.65mm | 1 | PCA9685
8 | U4;U5;U6;U7 | MSOP-8_3x3mm_Pitch0.65mm | 4 | BA4510FVM-GTR
9 | C1;C7;C9;C12;C14;C16;C18 | C_0603 | 7 | 100n
10 | C2;C8 | C_0603 | 2 | 10n
11 | C3;C5;C6;C10;C11;C13;C15;C17 | C_0603 | 8 | 10u
12 | C4 | C_0603 | 1 | 1u
13 | R1;R2;R5;R6;R7;R8;R9;R10;R14;R15;R19;R20;R24;R25 | R_0603 | 14 | 1M
14 | R3 | R_0603 | 1 | 240
15 | R4 | R_0603 | 1 | 750
16 | R11;R16;R21;R26 | R_0603 | 4 | 10k
17 | R12;R17;R22;R27 | R_0603 | 4 | 2.4k
18 | R13;R18;R23;R28 | R_0603 | 4 | 5.1k

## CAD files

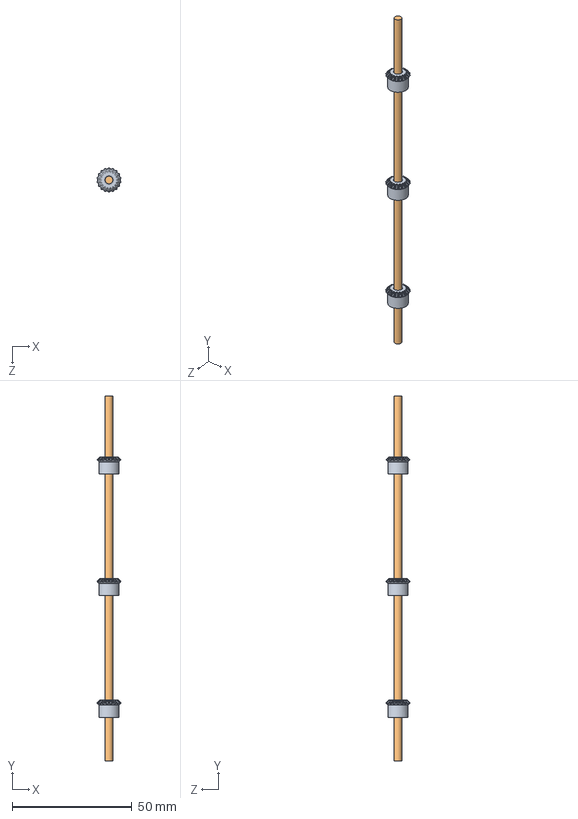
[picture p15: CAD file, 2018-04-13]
SLDWK/Axle.SLDASM
10.1 x 152.4 x 10.2 mm
Miter Gear x 3
Rod

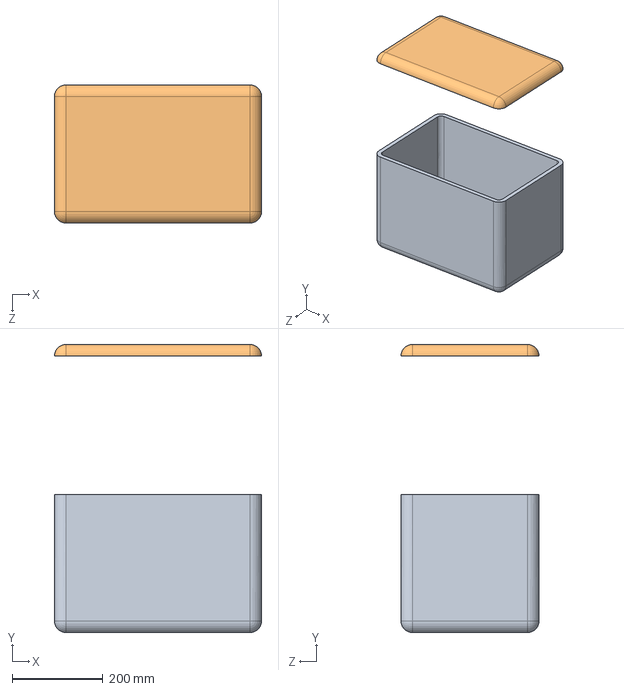
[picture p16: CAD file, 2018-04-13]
SLDWK/Room_Assem.SLDASM
457.2 x 635.5 x 304.8 mm
Room
Lid

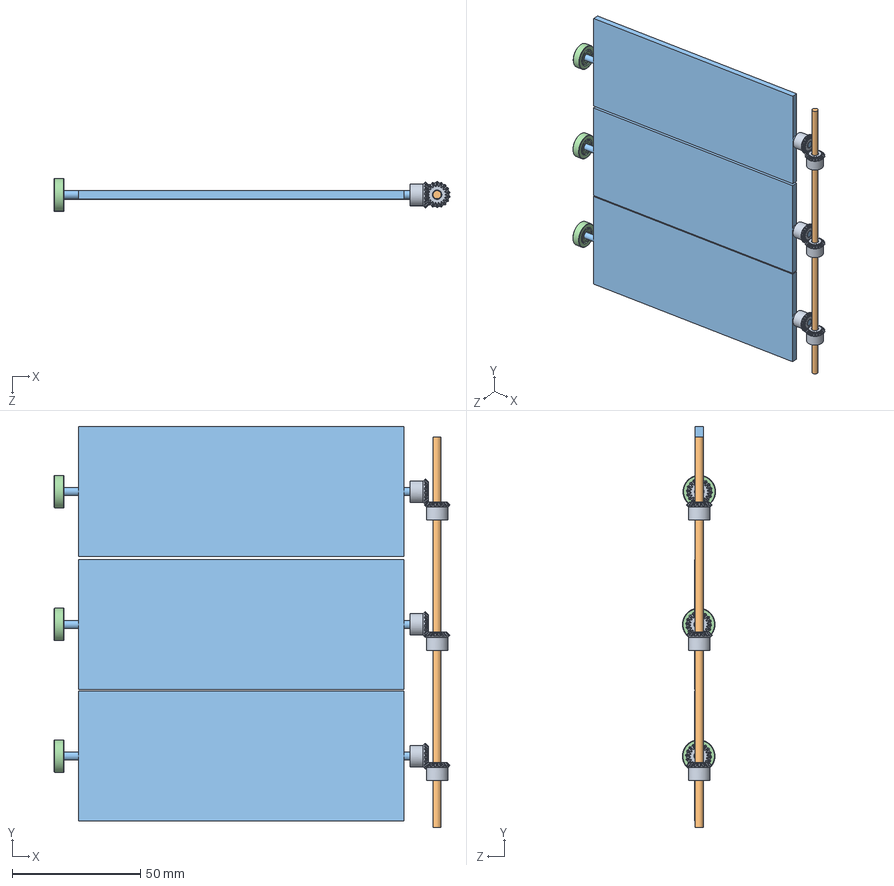
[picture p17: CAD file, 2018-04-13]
SLDWK/Blinds_Assem.SLDASM
154.5 x 156.4 x 12.9 mm
Miter Gear x 6
Rod
Blind x 3
6455K970_GENERAL PURPOSE PLASTIC BALL BEARING x 3

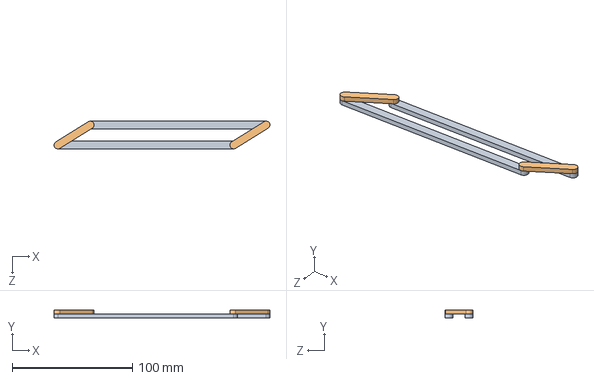
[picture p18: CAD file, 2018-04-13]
SLDWK/Blinds.SLDASM
179.4 x 6.35 x 23.1 mm
Parallel1 x 2
Parallel2 x 2

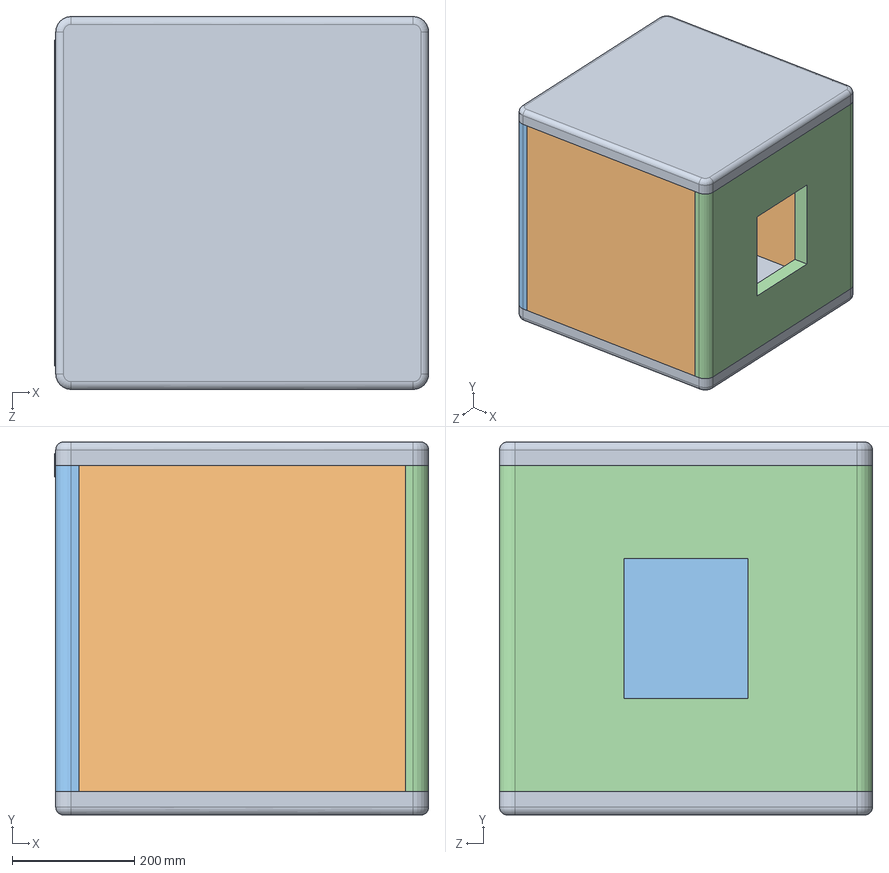
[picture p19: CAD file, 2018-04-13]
SLDWK/Room.SLDASM
611.9 x 609.6 x 609.6 mm
Base x 2
Front Wall x 2
Side Wall
Window
Hinge

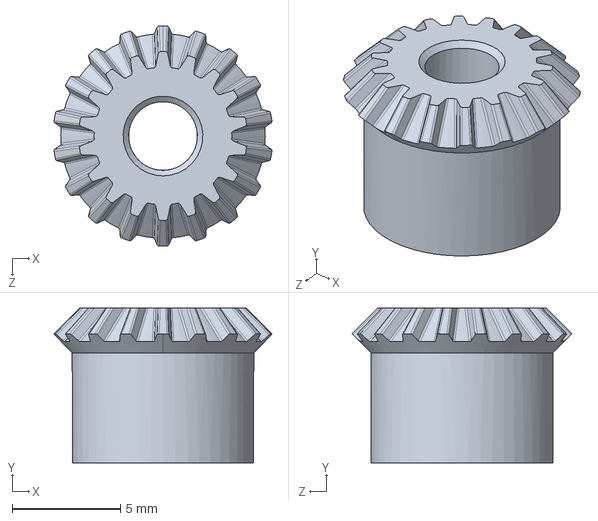
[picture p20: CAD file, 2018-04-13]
SLDWK/Miter Gear.SLDPRT
10.1 x 7.14 x 10.2 mm

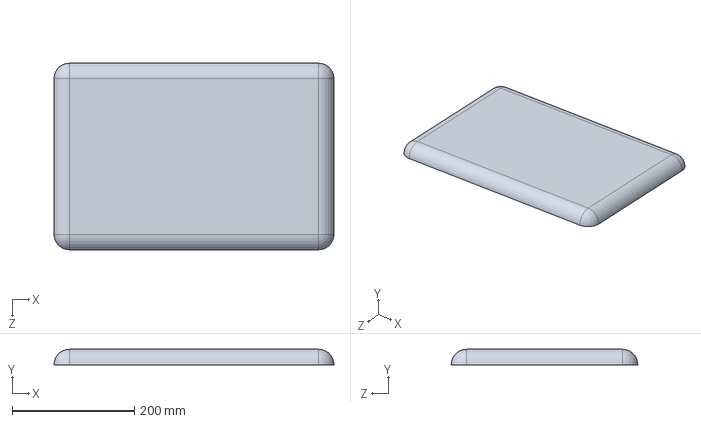
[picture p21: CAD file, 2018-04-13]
SLDWK/Lid.SLDPRT
457.2 x 25.4 x 304.8 mm

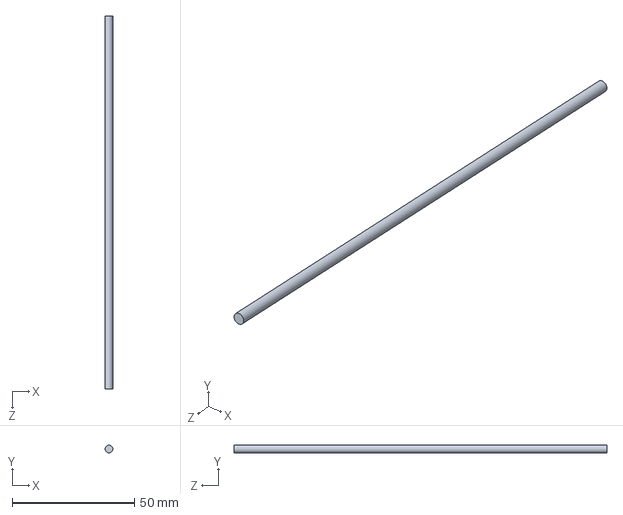
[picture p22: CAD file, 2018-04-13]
SLDWK/Rod.SLDPRT
3.17 x 3.17 x 152.4 mm

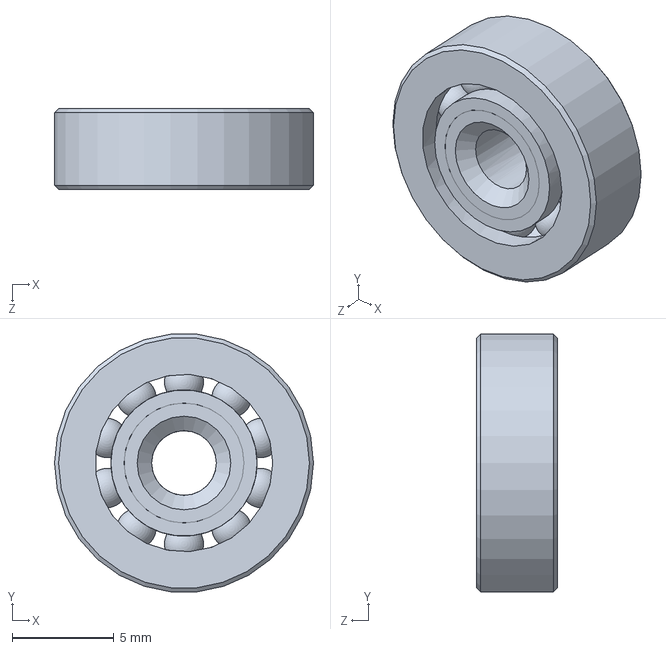
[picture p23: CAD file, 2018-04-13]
SLDWK/6455K970_GENERAL PURPOSE PLASTIC BALL BEARING.SLDPRT
12.7 x 12.6 x 3.97 mm

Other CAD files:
SLDWK/7297K110_PLASTIC GEAR FOR 90 DEG MOTION TRANSFER.SLDPRT
SLDWK/Room.SLDPRT

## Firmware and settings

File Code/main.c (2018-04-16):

/*
 * Controller.c
 *
 * Damon 'nomad' Boorstein
 * Lonnie L. Souder II
 * 04/13/2018
 *
 * This is the main implementation file for a control system
 * implemented on an MSP430FR2433 which controls the brightness
 * in a room using an array of LEDs and light sensors.
 */
 
 // uController Inits
#include <msp430.h> 
#include "initTA0.h"
#include "initADC.h"

// Data Structures
#include "Controller.h"


void initTA0();
void initADC();

unsigned int ADC_Result;

int main(void)
{
	WDTCTL = WDTPW | WDTHOLD;	// stop watchdog timer
	
	initTA0();
	initADC();
	initPWM();

	__bis_SR_register(LPM3_bits);
	return 0;
}

// Timer A0 interrupt service routine
#if defined(__TI_COMPILER_VERSION__) || defined(__IAR_SYSTEMS_ICC__)
#pragma vector = TIMER0_A0_VECTOR
__interrupt void Timer_A (void)
#elif defined(__GNUC__)
void __attribute__ ((interrupt(TIMER0_A0_VECTOR))) Timer_A (void)
#else
#error Compiler not supported!
#endif
{
    P1OUT ^= BIT0;
    TA0CCR0 += 50000;                             // Add Offset to TACCR0
}

// ADC interrupt service routine
#if defined(__TI_COMPILER_VERSION__) || defined(__IAR_SYSTEMS_ICC__)
#pragma vector=ADC_VECTOR
__interrupt void ADC_ISR(void)
#elif defined(__GNUC__)
void __attribute__ ((interrupt(ADC_VECTOR))) ADC_ISR (void)
#else
#error Compiler not supported!
#endif
{
    switch(__even_in_range(ADCIV,ADCIV_ADCIFG))
    {
        case ADCIV_NONE:
            break;
        case ADCIV_ADCOVIFG:
            break;
        case ADCIV_ADCTOVIFG:
            break;
        case ADCIV_ADCHIIFG:
            break;
        case ADCIV_ADCLOIFG:
            break;
        case ADCIV_ADCINIFG:
            break;
        case ADCIV_ADCIFG:
            ADC_Result = ADCMEM0;
            __bic_SR_register_on_exit(LPM0_bits);            // Clear CPUOFF bit from LPM0
            break;
        default:
            break;
    }
}

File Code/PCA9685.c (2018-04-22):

/*************************************************************************
 * pca9685.c
 *
 * This software is a devLib extension to wiringPi <http://wiringpi.com/>
 * and enables it to control the Adafruit PCA9685 16-Channel 12-bit
 * PWM/Servo Driver <http://www.adafruit.com/products/815> via I2C interface.
 *
 * Copyright (c) 2014 Reinhard Sprung
 *
 * If you have questions or improvements email me at
 * reinhard.sprung[at]gmail.com
 *
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
 * You can view the contents of the licence at <http://www.gnu.org/licenses/>.
 **************************************************************************
 */

#include <wiringPi.h>
#include <wiringPiI2C.h>

#include "pca9685.h"

// Setup registers
#define PCA9685_MODE1 0x0
#define PCA9685_PRESCALE 0xFE

// Define first LED and all LED. We calculate the rest
#define LED0_ON_L 0x6
#define LEDALL_ON_L 0xFA

#define PIN_ALL 16


// Declare
static void myPwmWrite(struct wiringPiNodeStruct *node, int pin, int value);
static void myOnOffWrite(struct wiringPiNodeStruct *node, int pin, int value);
static int myOffRead(struct wiringPiNodeStruct *node, int pin);
static int myOnRead(struct wiringPiNodeStruct *node, int pin);
int baseReg(int pin);


/**
 * Setup a PCA9685 device with wiringPi.
 *
 * pinBase: 	Use a pinBase > 64, eg. 300
 * i2cAddress:	The default address is 0x40
 * freq:		Frequency will be capped to range [40..1000] Hertz. Try 50 for servos
 */
int pca9685Setup(const int pinBase, const int i2cAddress, float freq)
{
	// Create a node with 16 pins [0..15] + [16] for all
	struct wiringPiNodeStruct *node = wiringPiNewNode(pinBase, PIN_ALL + 1);

	// Check if pinBase is available
	if (!node)
		return -1;

	// Check i2c address
	int fd = wiringPiI2CSetup(i2cAddress);
	if (fd < 0)
		return fd;

	// Setup the chip. Enable auto-increment of registers.
	int settings = wiringPiI2CReadReg8(fd, PCA9685_MODE1) & 0x7F;
	int autoInc = settings | 0x20;

	wiringPiI2CWriteReg8(fd, PCA9685_MODE1, autoInc);

	// Set frequency of PWM signals. Also ends sleep mode and starts PWM output.
	if (freq > 0)
		pca9685PWMFreq(fd, freq);


	node->fd			= fd;
	node->pwmWrite		= myPwmWrite;
	node->digitalWrite	= myOnOffWrite;
	node->digitalRead	= myOffRead;
	node->analogRead	= myOnRead;

	return fd;
}

/**
 * Sets the frequency of PWM signals.
 * Frequency will be capped to range [40..1000] Hertz. Try 50 for servos.
 */
void pca9685PWMFreq(int fd, float freq)
{
	// Cap at min and max
	freq = (freq > 1000 ? 1000 : (freq < 40 ? 40 : freq));

	// To set pwm frequency we have to set the prescale register. The formula is:
	// prescale = round(osc_clock / (4096 * frequency))) - 1 where osc_clock = 25 MHz
	// Further info here: http://www.nxp.com/documents/data_sheet/PCA9685.pdf Page 24
	int prescale = (int)(25000000.0f / (4096 * freq) - 0.5f);

	// Get settings and calc bytes for the different states.
	int settings = wiringPiI2CReadReg8(fd, PCA9685_MODE1) & 0x7F;	// Set restart bit to 0
	int sleep	= settings | 0x10;									// Set sleep bit to 1
	int wake 	= settings & 0xEF;									// Set sleep bit to 0
	int restart = wake | 0x80;										// Set restart bit to 1

	// Go to sleep, set prescale and wake up again.
	wiringPiI2CWriteReg8(fd, PCA9685_MODE1, sleep);
	wiringPiI2CWriteReg8(fd, PCA9685_PRESCALE, prescale);
	wiringPiI2CWriteReg8(fd, PCA9685_MODE1, wake);

	// Now wait a millisecond until oscillator finished stabilizing and restart PWM.
	delay(1);
	wiringPiI2CWriteReg8(fd, PCA9685_MODE1, restart);
}

/**
 * Set all leds back to default values (: fullOff = 1)
 */
void pca9685PWMReset(int fd)
{
	wiringPiI2CWriteReg16(fd, LEDALL_ON_L	 , 0x0);
	wiringPiI2CWriteReg16(fd, LEDALL_ON_L + 2, 0x1000);
}

/**
 * Write on and off ticks manually to a pin
 * (Deactivates any full-on and full-off)
 */
void pca9685PWMWrite(int fd, int pin, int on, int off)
{
	int reg = baseReg(pin);

	// Write to on and off registers and mask the 12 lowest bits of data to overwrite full-on and off
	wiringPiI2CWriteReg16(fd, reg	 , on  & 0x0FFF);
	wiringPiI2CWriteReg16(fd, reg + 2, off & 0x0FFF);
}

/**
 * Reads both on and off registers as 16 bit of data
 * To get PWM: mask each value with 0xFFF
 * To get full-on or off bit: mask with 0x1000
 * Note: ALL_LED pin will always return 0
 */
void pca9685PWMRead(int fd, int pin, int *on, int *off)
{
	int reg = baseReg(pin);

	if (on)
		*on  = wiringPiI2CReadReg16(fd, reg);
	if (off)
		*off = wiringPiI2CReadReg16(fd, reg + 2);
}

/**
 * Enables or deactivates full-on
 * tf = true: full-on
 * tf = false: according to PWM
 */
void pca9685FullOn(int fd, int pin, int tf)
{
	int reg = baseReg(pin) + 1;		// LEDX_ON_H
	int state = wiringPiI2CReadReg8(fd, reg);

	// Set bit 4 to 1 or 0 accordingly
	state = tf ? (state | 0x10) : (state & 0xEF);

	wiringPiI2CWriteReg8(fd, reg, state);

	// For simplicity, we set full-off to 0 because it has priority over full-on
	if (tf)
		pca9685FullOff(fd, pin, 0);
}

/**
 * Enables or deactivates full-off
 * tf = true: full-off
 * tf = false: according to PWM or full-on
 */
void pca9685FullOff(int fd, int pin, int tf)
{
	int reg = baseReg(pin) + 3;		// LEDX_OFF_H
	int state = wiringPiI2CReadReg8(fd, reg);

	// Set bit 4 to 1 or 0 accordingly
	state = tf ? (state | 0x10) : (state & 0xEF);

	wiringPiI2CWriteReg8(fd, reg, state);
}

/**
 * Helper function to get to register
 */
int baseReg(int pin)
{
	return (pin >= PIN_ALL ? LEDALL_ON_L : LED0_ON_L + 4 * pin);
}




//------------------------------------------------------------------------------------------------------------------
//
//	WiringPi functions
//
//------------------------------------------------------------------------------------------------------------------




/**
 * Simple PWM control which sets on-tick to 0 and off-tick to value.
 * If value is <= 0, full-off will be enabled
 * If value is >= 4096, full-on will be enabled
 * Every value in between enables PWM output
 */
static void myPwmWrite(struct wiringPiNodeStruct *node, int pin, int value)
{
	int fd   = node->fd;
	int ipin = pin - node->pinBase;

	if (value >= 4096)
		pca9685FullOn(fd, ipin, 1);
	else if (value > 0)
		pca9685PWMWrite(fd, ipin, 0, value);	// (Deactivates full-on and off by itself)
	else
		pca9685FullOff(fd, ipin, 1);
}

/**
 * Simple full-on and full-off control
 * If value is 0, full-off will be enabled
 * If value is not 0, full-on will be enabled
 */
static void myOnOffWrite(struct wiringPiNodeStruct *node, int pin, int value)
{
	int fd   = node->fd;
	int ipin = pin - node->pinBase;

	if (value)
		pca9685FullOn(fd, ipin, 1);
	else
		pca9685FullOff(fd, ipin, 1);
}

/**
 * Reads off registers as 16 bit of data
 * To get PWM: mask with 0xFFF
 * To get full-off bit: mask with 0x1000
 * Note: ALL_LED pin will always return 0
 */
static int myOffRead(struct wiringPiNodeStruct *node, int pin)
{
	int fd   = node->fd;
	int ipin = pin - node->pinBase;

	int off;
	pca9685PWMRead(fd, ipin, 0, &off);

	return off;
}
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

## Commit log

2018-03-30 Drafted schematic for light sense and source board
    [lightBoard.kicad_pcb, lightBoard.sch]
2018-04-01 Board layout finished.
    [_saved_lightBoard.sch]
2018-04-07 Minor file restructuring
    [_saved_lightBoard.sch]
2018-04-07 Minor file restructuring... I mean it this time.
    [lightBoard.kicad_pcb, lightBoard.sch]
2018-04-07 Started on central board
    [LightController.kicad_pcb, LightController.sch, lightInterface.sch]
2018-04-07 Finished LED driver for controller daughter card
    [LightController.sch, lightInterface.sch, transimpedanceAmp.sch]
2018-04-08 Finished CentralBoard schematic and added hardware description section to the README
    [LightController.sch, lightInterface.sch, transimpedanceAmp.sch]
2018-04-08 Created project specific footprint library. Placed all components. Started traces.
    [LightController.kicad_pcb, LightController.sch, transimpedanceAmp.sch]
2018-04-08 Changed transimpedance amps to 5V supply. Finished routing CentralBoard
    [LightController.kicad_pcb, lightInterface.sch, transimpedanceAmp.sch]
2018-04-09 Generated Gerbers
    [LightController-B.Cu.gbl, LightController-B.Mask.gbs, LightController-B.Paste.gbp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]
2018-04-09 Generated BOMs
    [LightController_BOM.csv, lightBoard_BOM.csv]
2018-04-11 Fixed transimpedance amps in schematic
    [LightController.sch, lightInterface.sch, transimpedanceAmp.sch]
2018-04-11 Fixed transimpedance amp on layout and generated new Gerbers.
    [LightController-B.Cu.gbl, LightController-B.Mask.gbs, LightController-B.Paste.gbp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]
2018-04-13 Uploading SOLIDWORKS folder for little to no reason
    [6455K970_GENERAL PURPOSE PLASTIC BALL BEARING.SLDPRT, 7297K110_PLASTIC GEAR FOR 90 DEG MOTION TRANSFER.SLDPRT, Axle.SLDASM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]
2018-04-13 Uploading a bunch of misc files and .gitignore
    [LightController_BOM.xlsx]
2018-04-16 Moved BOM xlsx to proper folder.
    [LightController_BOM.xlsx]
2018-04-16 Added functions for updating the driver signal from the Controller.
2018-04-16 Fixed lack of headers. Cleaned up titles.
    [initADC.c, main.c]
2018-04-20 Added I2C headers
2018-05-10 Refs & schematics -> Documentation. New README in SLDWK/.
    [LightBoard_BOM.csv, LightController_BOM.csv]

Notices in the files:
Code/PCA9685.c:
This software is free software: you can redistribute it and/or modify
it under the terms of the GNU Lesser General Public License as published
